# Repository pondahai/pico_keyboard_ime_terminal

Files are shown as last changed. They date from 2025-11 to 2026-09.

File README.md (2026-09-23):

# pico_keyboard_ime_terminal

**版本:** 1.8.0 (多分頁 UI 重構)  
**建置:** 里程碑 3.1 除錯建置 (v2.2 - Tag ID 記錄)

本文件旨在深入說明 PicoType Keyboard 韌體的內部架構、核心演算法與設計理念，主要供開發者與技術愛好者參考。

## 核心技術特點

此專案在資源有限的微控制器 (MCU) 上實現了複雜的中文輸入、圖形化介面與網路通訊功能，其核心技術包含以下幾點：

### 1. 模組化 UI 框架 (分頁系統)

為了應對日益複雜的功能，v1.8.0 版本引入了一套基於函式指標 (Function Pointer) 的分頁系統，取代了原有的 `enum` 狀態機。

*   **`Tab` 結構體:**
    ```c++
    struct Tab {
      const char* name;
      DrawFunction draw_func;
      InputHandler input_handler;
    };
    ```    此結構體定義了一個 UI 分頁，其中包含分頁名稱、一個指向其專屬**繪圖函式**的指標 (`draw_func`)，以及一個指向其**按鍵處理函式**的指標 (`input_handler`)。

*   **運作機制:**
    系統透過一個全域索引 `g_current_tab_index` 來追蹤目前作用中的分頁。主迴圈中的 `drawUI()` 和 `processKeyEvent()` 函式會根據此索引，從 `g_tabs[]` 陣列中呼叫對應的繪圖與輸入處理函式。
    ```c++
    // 繪圖時
    g_tabs[g_current_tab_index].draw_func();

    // 處理按鍵時
    g_tabs[g_current_tab_index].input_handler(finalKeyCode);
    ```

*   **優勢:** 這種設計具備高度可擴展性。新增一個功能分頁（例如「設定」或「地圖」）只需：
    1.  撰寫其對應的繪圖與輸入處理函式。
    2.  在 `g_tabs[]` 陣列中新增一筆 `Tab` 實體。
    無需修改核心的 UI 調度邏輯。

### 2. 高效能中文注音輸入法引擎 (IME)

`ImeEngine` 類別是實現中文輸入的核心。它採用了針對嵌入式系統優化的兩階段查詢演算法，以在極低的記憶體佔用下實現快速的字詞查詢。

*   **資料結構:** 所有輸入法資料（注音索引、字詞庫）都被預先處理並儲存在 `PROGMEM`（程式記憶體）中，由 `picotype_data_optimized.h` 引入。
    *   `zhuyin_idx_opt[]`: 注音查詢索引表。每一項包含一個指向字詞庫中「查詢鍵」的指標 (`key_offset`) 和長度，以及指向候選字詞資料的指標 (`data_offset`) 和長度。此索引表**已預先按查詢鍵的字母序排序**。
    *   `zhuyin_pool_opt[]`: 包含所有查詢鍵與候選字詞的巨大字串池。

*   **查詢流程:**
    1.  **按鍵轉注音:** `mapKeyToBopomofo()` 將鍵盤輸入 (如 "su3") 轉換為 UTF-8 注音符號 (如 "ㄙㄨˇ")，用於在螢幕上顯示。
    2.  **注音格式化為查詢鍵:** `formatBopomofoToKey()` 將注音符號轉換為用於在索引中查找的標準化查詢鍵 (如將 "ㄙㄨˇ" 轉換為 "ㄙㄨ3")。聲調被統一轉換為數字 `1`-`5` 並置於尾部，以利於排序與搜尋。
    3.  **二分搜尋 (Binary Search):** `binarySearch()` 函式在已排序的 `zhuyin_idx_opt` 索引表中對查詢鍵執行二分搜尋。這是在數千筆資料中實現毫秒級查找的關鍵。
    4.  **提取候選字:** 一旦找到匹配的索引記錄，便根據記錄中的 `data_offset` 和 `data_len` 從 `zhuyin_pool_opt` 字串池中直接讀取對應的候選字詞字串，並返回給上層 UI 顯示。

### 3. 優化的中文字型渲染

`FontRenderer` 類別負責將 UTF-8 編碼的字串（包含 ASCII 與中文字元）渲染到 ILI9341 螢幕上。

*   **資料結構:**
    *   `font_map_opt[]`: 字型映射表。每一項包含一個 Unicode 碼點，以及該字元在點陣資料池中的偏移量、寬度、高度和繪製偏移等資訊。此映射表**已預先按 Unicode 碼點排序**。
    *   `font_bitmap_data_opt[]`: 儲存所有字元點陣圖資料的巨型位元組陣列。

*   **渲染流程:**
    1.  **UTF-8 解碼:** `decodeUtf8()` 將輸入的字串逐字元解碼為 32 位元的 Unicode 碼點。
    2.  **ASCII 快速路徑:** 如果 Unicode 小於 128，則直接使用 `Adafruit_GFX` 內建的字型進行繪製，效率更高。
    3.  **中文字元查找:** 對於非 ASCII 字元，`findChar()` 函式會在 `font_map_opt` 中執行**二分搜尋**，快速定位該 Unicode 對應的字型資訊。
    4.  **點陣繪製:** 找到字元資訊後，`drawChar()` 函式會使用 `memcpy_P` 從 `PROGMEM` 中將點陣資料高效地複製到一個 RAM 緩衝區 (`g_char_bitmap_buffer`)，然後逐點將其繪製到 TFT 螢幕上。

### 4. Meshtastic Protobuf 通訊協定處理

裝置透過 UART 與 Meshtastic 節點通訊，所有資料交換均遵循其 Protobuf 序列化格式。

*   **封包結構:** Meshtastic 韌體使用一個簡單的封包格式來傳輸 Protobuf 資料：
    `[0x94, 0xc3]` (起始位元組) + `[Len_H, Len_L]` (2位元組長度) + `[Payload]` (Protobuf 資料)

*   **接收與解碼 (`handleProtoRx`):**
    此函式是一個狀態機，用於解析 UART 上接收到的位元組流。
    1.  等待 `0x94` 和 `0xc3` 起始位元組。
    2.  讀取接下來的兩個位元組，組合成承載資料的長度。
    3.  讀取指定長度的承載資料到 `proto_rx_buffer`。
    4.  使用 `nanopb` 的 `pb_decode()` 函式將緩衝區內的二進位資料反序列化為 `meshtastic_FromRadio` 結構體。
    5.  根據結構體中的 `which_payload_variant` 欄位（Tag ID），判斷封包類型（如 `my_info_tag`, `node_info_tag`, `packet_tag` 等），並分派給相應的處理邏輯（如更新節點資料庫、在聊天視窗顯示訊息等）。

*   **編碼與傳送:**
    傳送資料的流程相反。例如 `sendProtobufTextMessage()`:
    1.  建立一個 `meshtastic_ToRadio` 結構體。
    2.  填充需要傳送的資料（目標 ID、訊息內容等）。
    3.  使用 `nanopb` 的 `pb_encode()` 函式將結構體序列化為位元組流，存入 `proto_tx_buffer`。
    4.  依照上述封包結構，加上起始位元組和長度資訊，透過 `Serial1.write()` 傳送出去。

### 5. 硬體抽象 (鍵盤掃描)

鍵盤矩陣的掃描是透過兩顆移位暫存器（74HC595 負責輸出掃描訊號，74HC165 負責讀取按鍵狀態）完成的。

*   `updateKeyboardAndLeds_TwoPulse()` 函式負責整個掃描週期。它透過 `shiftOut` 向 74HC595 傳送資料來依序啟用鍵盤的每一列，同時也順便更新了 LED 的狀態。
*   在啟用每一列後，透過自訂的 `myShiftIn` 函式從 74HC165 讀回該列上所有按鍵的狀態。
*   為了處理硬體設計上的時序問題，函式中使用了兩次 Latch Pin 的脈衝 (`digitalWrite(LATCH_PIN, ...)`), 確保資料能被正確鎖存和讀取。

## 程式碼結構

*   **全域物件與變數:**
    *   `tft`, `renderer`, `ime`: 核心功能的類別實體。
    *   `g_tabs[]`, `g_current_tab_index`: UI 框架的核心。
    *   `g_node_db[]`, `g_channels[]`: Meshtastic 網路的本地資料快取。
    *   `inputBuffer_keys`, `editor_content`: 輸入與編輯區的狀態緩衝區。

*   **主要流程 (`setup()` & `loop()`):**
    *   `setup()`: 初始化硬體、序列埠、顯示器，並載入初始狀態。
    *   `loop()`:
        1.  處理 Protobuf/Terminal 的序列埠接收。
        2.  定期執行 Protobuf 的心跳與握手重試。
        3.  呼叫 `updateKeyboardAndLeds_TwoPulse()` 掃描鍵盤。
        4.  比較本次與上次的按鍵狀態，若有變化則呼叫 `processKeyEvent()` 進行處理。
        5.  更新 `lastKeyState` 狀態。
        6.  若 `needs_redraw` 旗標為真，則呼叫 `drawUI()` 更新螢幕。

## 編譯與依賴

*   **函式庫:**
    *   `Adafruit_GFX` & `Adafruit_ILI9341`: 顯示驅動。
    *   `nanopb`: Google Protobuf 的嵌入式 C 語言實現。
*   **核心資料檔案:**
    *   `picotype_data_optimized.h`: **極為關鍵**。此檔案包含了由外部工具預先處理好的字型點陣、字元映射表、注音索引與字詞庫。缺少此檔案，專案將無法編譯。
*   **Protobuf 生成檔案:**
    *   `mesh.pb.h`, `channel.pb.h` 等檔案需要從 Meshtastic 專案的 `.proto` 定義檔，使用 `nanopb_generator.py` 工具生成。

## 硬體 Pinout

| 功能 | 接腳 (GPIO) | 說明 |
| :--- | :--- | :--- |
| **TFT 顯示器** | | |
| CS | 17 | 片選 |
| RST | 21 | 重置 |
| DC | 20 | 資料/命令 |
| BLK | 22 | 背光控制 |
| **鍵盤移位暫存器** | | |
| DATA_OUT | 15 | 序列資料輸出 (至 74HC595) |
| LATCH | 14 | 鎖存訊號 |
| CLOCK | 26 | 時脈訊號 |
| DATA_IN | 27 | 序列資料輸入 (自 74HC165) |
| **UART 通訊** | | |
| TX | 0 | 至 Meshtastic 裝置的 RX |
| RX | 1 | 至 Meshtastic 裝置的 TX |

## 授權

本專案自身的程式碼採 **MIT**，見 [`LICENSE`](LICENSE)。

`picotype_data_optimized.h` 是**衍生資料**，同時包含第三方的字型點陣與注音碼表，
其聲明必須隨著散布。完整內容見 [`THIRD_PARTY_NOTICES.md`](THIRD_PARTY_NOTICES.md)，
摘要如下：

| 成分 | 上游 | 授權 |
| :--- | :--- | :--- |
| 注音碼表（`zhuyin_*` 陣列） | [McBopomofo](https://github.com/openvanilla/McBopomofo)（小麥注音輸入法） | MIT，Copyright (c) 2011-2026 Mengjuei Hsieh et al. |
| 中文字型（`font_*` 陣列） | Cubic 11（俐方體十一號）+ Fusion Pixel 12px | SIL OFL 1.1 |

碼表使用的是 `BPMFBase.txt`（單字注音）與 `BPMFPunctuations.txt`（標點），
兩者在上游皆無額外出處註記。帶有 libtabe（BSD）血統的是多字詞庫
`BPMFMappings.txt` —— **本專案未使用**（這裡是單字候選，不是詞庫）。

> ⚠️ **關於編譯後的韌體**：本 repo 不含 `.pb.c` / `.pb.h`，需自行以
> `nanopb_generator.py` 從 [meshtastic/protobufs](https://github.com/meshtastic/protobufs)
> 產生，而該專案為 **GPL-3.0**。因此**編譯出來的韌體二進位檔整體是 GPL-3.0**。
> MIT 與 GPL-3.0 相容，此組合合法，只是散布該二進位檔時須遵守 GPL-3.0。

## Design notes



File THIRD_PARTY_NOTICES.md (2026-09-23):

# Third-Party Notices

本專案的 `picotype_data_optimized.h` 是**衍生資料**,不是手寫的程式碼。
它由 [ime-charset-font-bitmap](https://github.com/pondahai/ime-charset-font-bitmap)
的建置管線產生,內容同時包含第三方的**字型點陣資料**與**注音碼表資料**。

散布本專案(含編譯後的韌體)時,以下聲明必須隨著一起散布。

---

## 1. 注音輸入法碼表 — McBopomofo(小麥注音輸入法)

| | |
|---|---|
| 上游 | https://github.com/openvanilla/McBopomofo |
| 授權 | MIT License |
| 著作權 | Copyright (c) 2011-2026 Mengjuei Hsieh et al. |

### 實際使用的檔案

| 檔案 | 內容 | 有無額外上游出處 |
|---|---|---|
| `Source/Data/BPMFBase.txt` | 單字注音對應 | 無 —— 適用 McBopomofo 的 MIT |
| `Source/Data/BPMFPunctuations.txt` | 標點符號對應 | 無 —— 適用 McBopomofo 的 MIT |

### 明確未使用的檔案

`Source/Data/BPMFMappings.txt`(2–6 字的多字詞庫)**未被使用**。

這點值得寫明:依 McBopomofo 的 `Source/Data/README.md`,該檔案
*"Originally simplified from tsi.src of libtabe (BSD Licensed) with modifications"*
——它帶有 libtabe 的 BSD 血統。

本專案的輸入法是**單字候選**而非詞庫,只取用了 `BPMFBase.txt` 與
`BPMFPunctuations.txt`,因此不涉及 libtabe,亦無 BSD 條款需要遵循。

### 資料在本專案中的形式

原始碼表為文字格式,經建置管線轉換為「索引 + 資料池」的二進位結構,
以 `zhuyin_idx_raw_opt[]` 與 `zhuyin_pool_opt[]` 兩個陣列存在於
`picotype_data_optimized.h`。此為格式轉換,內容仍為 McBopomofo 的衍生著作。

### MIT License 全文

```
MIT License

Copyright (c) 2011-2026 Mengjuei Hsieh et al.

Permission is hereby granted, free of charge, to any person obtaining a copy
of this software and associated documentation files (the "Software"), to deal
in the Software without restriction, including without limitation the rights
to use, copy, modify, merge, publish, distribute, sublicense, and/or sell
copies of the Software, and to permit persons to whom the Software is
furnished to do so, subject to the following conditions:

The above copyright notice and this permission notice shall be included in all
copies or substantial portions of the Software.

THE SOFTWARE IS PROVIDED "AS IS", WITHOUT WARRANTY OF ANY KIND, EXPRESS OR
IMPLIED, INCLUDING BUT NOT LIMITED TO THE WARRANTIES OF MERCHANTABILITY,
FITNESS FOR A PARTICULAR PURPOSE AND NONINFRINGEMENT. IN NO EVENT SHALL THE
AUTHORS OR COPYRIGHT HOLDERS BE LIABLE FOR ANY CLAIM, DAMAGES OR OTHER
LIABILITY, WHETHER IN AN ACTION OF CONTRACT, TORT OR OTHERWISE, ARISING FROM,
OUT OF OR IN CONNECTION WITH THE SOFTWARE OR THE USE OR OTHER DEALINGS IN THE
SOFTWARE.
```

---

## 2. 中文字型點陣資料

`picotype_data_optimized.h` 內的 `font_map_raw_opt[]` 與
`font_bitmap_data_1bpp[]` 是由下列字型光柵化產生的點陣資料。

| 字型 | 授權 | 角色 |
|---|---|---|
| [Cubic 11](https://github.com/ACh-K/Cubic-11)(俐方體十一號)v1.430 | SIL OFL 1.1 | 主字型 |
| [Fusion Pixel 12px zh_hant](https://github.com/TakWolf/fusion-pixel-font) | SIL OFL 1.1 | fallback |

依 SIL OFL 1.1,散布衍生資料時須隨附授權文字。完整的字型出處、版本固定理由
與保留字型名稱說明,見上游 repo 的 `fonts/LICENSES/ATTRIBUTION.md`。

> **保留字型名稱(Reserved Font Name)**:Cubic 保留「Cubic」「俐方體」。
> 本專案的產出不得以這些名稱對外呈現為字型名,故衍生檔案採中性命名
> (`picotype_*`)。

---

## 3. Meshtastic protobuf 與 Nanopb(本 repo 未收錄,但編譯時必要)

本 repo **不含**任何 `.pb.c` / `.pb.h` 或 nanopb 原始碼 ——
依 README,這些檔案由使用者自行以 `nanopb_generator.py` 從上游產生。

| 元件 | 上游 | 授權 |
|---|---|---|
| Meshtastic `.proto` 定義 | [meshtastic/protobufs](https://github.com/meshtastic/protobufs) | **GPL-3.0** |
| Nanopb(執行期與產生器) | [nanopb/nanopb](https://github.com/nanopb/nanopb) | Zlib,Copyright (c) 2011 Petteri Aimonen |

> ⚠️ **關於編譯後的韌體**
>
> 本 repo 自身的程式碼採 MIT。但 Meshtastic 的 protobuf 定義為 GPL-3.0,
> 因此**把本專案與那些產生檔一起編譯出來的韌體二進位檔,整體是 GPL-3.0**。
>
> MIT 與 GPL-3.0 相容(MIT 程式碼可被納入 GPL 作品),所以這個組合是合法的
> ——只是散布該二進位檔時要遵守 GPL-3.0,而不是 MIT。

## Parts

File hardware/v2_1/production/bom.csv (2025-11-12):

Designator | Footprint | Quantity | Value | LCSC Part #
BT1 | JST_PH_B2B-PH-K_1x02_P2.00mm_Vertical | 1 | Li-Poly PH2.0
C1, C2, C3 | 0805 | 3 | 100n
C10, C11, C9 | 0805 | 3 | 100nF
C12 | 1206 | 1 | 100nF
C4 | 0805 | 1 | 33n
C5, C6 | 0805 | 2 | 100n/10u
C7 | 0805 | 1 | 1u
C8 | 0805 | 1 | 1u/NC
D1, D10, D11, D12, D13, D14, D15, D16, D17, D18, D19, D2, D20, D21, D22, D23, D24, D25, D26, D27, D28, D29, D3, D30, D31, D32, D33, D34, D35, D36, D37, D38, D39, D4, D40, D41, D42, D43, D44, D45, D46, D47, D48, D49, D5, D50, D51, D52, D53, D54, D55, D56, D57, D58, D59, D6, D60, D61, D62, D7, D8, D9 | D_0805_JUMPER | 62 | 1N4148
D63 | LED_D3.0mm_Clear | 1 | ㄅ
D64 | LED_D3.0mm_Clear | 1 | ENG
D65 | 0805 | 1 | charge
J1 | PinHeader_1x07_P2.54mm_Horizontal | 1 | Conn_01x07
J10 | sd-card | 1 | Micro_SD_Card
J2 | STP0280A1-240320 | 1 | STP0280A1-240320-18P
J3 | PinSocket_1x07_P2.54mm_Horizontal | 1 | KEYBOARD
J4 | PinSocket_1x04_P2.54mm_Horizontal | 1 | UART
J5 | PinHeader_1x04_P2.54mm_Vertical | 1 | I2C Oled screen
J6 | audiojack-3.5mm-5p | 1 | AudioJack3_SwitchTR
J7 | SolderWire-0.1sqmm_1x02_P3.6mm_D0.4mm_OD1mm | 1 | speaker
J8 | Hirose_DF13-02P-1.25DSA_1x02_P1.25mm_Vertical | 1 | speaker
J9 | PinHeader_1x04_P2.54mm_Vertical | 1 | GPS Pins
M1 | HT-RA62 RA-01SH LoRa radio | 1 | HT-RA62_/_RA-01SH_LoRa_radio
M2 | ProMicro nrf52840 | 1 | ProMicro_NRF52840
M3 | LoRa-ESP32-V3 | 1 | ESP32_LORA_V3
M4 | T114 | 1 | T114_V2
Q1 | SOT-23_Handsoldering | 1 | 2N7002
Q2 | SOT-23_Handsoldering | 1 | DMG2305UX
R1, R2 | R_Axial_DIN0204_L3.6mm_D1.6mm_P7.62mm_Horizontal_0805 | 2 | R_US
R10 | 0805 | 1 | 0/15k
R11 | 0805 | 1 | 0/NC
R12, R13 | 0805 | 2 | 12k/100
R14 | 0805 | 1 | NC/10k
R15, R18 | 0805 | 2 | 10k
R16, R17 | 0805 | 2 | 10M
R19 | 1206 | 1 | 1k
R3 | 0805 | 1 | 330
R4, R7 | 0805 | 2 | 10k
R5 | 0805 | 1 | 5k1
R6 | 0805 | 1 | 1k
R8 | 0805 | 1 | 270
R9 | 0805 | 1 | NC/150
RN1, RN2 | R_Array_Convex_4x0603 | 2 | 10K
RN3 | R_Array_Convex_4x0603 | 1 | 10
RN4, RN5 | R_Array_Convex_4x0603 | 2 | 47k
RV1 | potentiometre disk 5pin | 1 | 10k
SW1 | SW_Push_1P1T_NO_CK_KSC7xxJ | 1 | 1 ! ㄅ
SW10 | SW_Push_1P1T_NO_CK_KSC7xxJ | 1 | E ㄍ
SW11 | SW_Push_1P1T_NO_CK_KSC7xxJ | 1 | D ㄎ
SW12 | SW_Push_1P1T_NO_CK_KSC7xxJ | 1 | C ㄏ
SW13 | SW_Push_1P1T_NO_CK_KSC7xxJ | 1 | 4 $ ˋ
SW14 | SW_Push_1P1T_NO_CK_KSC7xxJ | 1 | R ㄐ
SW15 | SW_Push_1P1T_NO_CK_KSC7xxJ | 1 | F ㄑ
SW16 | SW_Push_1P1T_NO_CK_KSC7xxJ | 1 | V ㄒ
SW17 | SW_Push_1P1T_NO_CK_KSC7xxJ | 1 | 5 % ㄓ
SW18 | SW_Push_1P1T_NO_CK_KSC7xxJ | 1 | T ㄔ
SW19 | SW_Push_1P1T_NO_CK_KSC7xxJ | 1 | G ㄕ
SW2 | SW_Push_1P1T_NO_CK_KSC7xxJ | 1 | Q ㄆ
SW20 | SW_Push_1P1T_NO_CK_KSC7xxJ | 1 | B ㄖ
SW21 | SW_Push_1P1T_NO_CK_KSC7xxJ | 1 | 6 ^ ˊ
SW22 | SW_Push_1P1T_NO_CK_KSC7xxJ | 1 | Y ㄗ
SW23 | SW_Push_1P1T_NO_CK_KSC7xxJ | 1 | H ㄘ
SW24 | SW_Push_1P1T_NO_CK_KSC7xxJ | 1 | N ㄙ
SW25 | SW_Push_1P1T_NO_CK_KSC7xxJ | 1 | 7 & ˙
SW26 | SW_Push_1P1T_NO_CK_KSC7xxJ | 1 | U ㄧ
SW27 | SW_Push_1P1T_NO_CK_KSC7xxJ | 1 | J ㄨ
SW28 | SW_Push_1P1T_NO_CK_KSC7xxJ | 1 | M ㄩ
SW29 | SW_Push_1P1T_NO_CK_KSC7xxJ | 1 | 8 * ㄚ
SW3 | SW_Push_1P1T_NO_CK_KSC7xxJ | 1 | A ㄇ
SW30 | SW_Push_1P1T_NO_CK_KSC7xxJ | 1 | I ㄛ
SW31 | SW_Push_1P1T_NO_CK_KSC7xxJ | 1 | K ㄜ
SW32 | SW_Push_1P1T_NO_CK_KSC7xxJ | 1 | , < ㄝ
SW33 | SW_Push_1P1T_NO_CK_KSC7xxJ | 1 | 9 ( ㄞ
SW34 | SW_Push_1P1T_NO_CK_KSC7xxJ | 1 | O ㄟ
SW35 | SW_Push_1P1T_NO_CK_KSC7xxJ | 1 | L ㄠ
SW36 | SW_Push_1P1T_NO_CK_KSC7xxJ | 1 | . > ㄡ
SW37 | SW_Push_1P1T_NO_CK_KSC7xxJ | 1 | 0 ) ㄢ
SW38 | SW_Push_1P1T_NO_CK_KSC7xxJ | 1 | P ㄣ
SW39 | SW_Push_1P1T_NO_CK_KSC7xxJ | 1 | ; : ㄤ
SW4 | SW_Push_1P1T_NO_CK_KSC7xxJ | 1 | Z ㄈ
SW40 | SW_Push_1P1T_NO_CK_KSC7xxJ | 1 | / ? ㄥ
SW41 | SW_Push_1P1T_NO_CK_KSC7xxJ | 1 | - _ ㄦ
SW42 | SW_Push_1P1T_NO_CK_KSC7xxJ | 1 | [ {
SW43 | SW_Push_1P1T_NO_CK_KSC7xxJ | 1 | ' "
SW44 | SW_Push_1P1T_NO_CK_KSC7xxJ | 1 | SHIFT
SW45 | SW_Push_1P1T_NO_CK_KSC7xxJ | 1 | = +
SW46 | SW_Push_1P1T_NO_CK_KSC7xxJ | 1 | ] }
SW47 | SW_Push_1P1T_NO_CK_KSC7xxJ | 1 | ENTER
SW48 | SW_Push_1P1T_NO_CK_KSC7xxJ | 1 | SPACE
SW49 | SW_Push_1P1T_NO_CK_KSC7xxJ | 1 | ` ~
SW5 | SW_Push_1P1T_NO_CK_KSC7xxJ | 1 | 2 @ ㄉ
SW50 | SW_Push_1P1T_NO_CK_KSC7xxJ | 1 | TAB
SW51 | SW_Push_1P1T_NO_CK_KSC7xxJ | 1 | CAPS
SW52 | SW_Push_1P1T_NO_CK_KSC7xxJ | 1 | CTRL
SW53 | SW_Push_1P1T_NO_CK_KSC7xxJ | 1 | ALT
SW54 | SW_Push_1P1T_NO_CK_KSC7xxJ | 1 | BACK
SW55 | SW_Push_1P1T_NO_CK_KSC7xxJ | 1 | \
SW56 | SW_Push_1P1T_NO_CK_KSC7xxJ | 1 | PGUP
SW57 | SW_Push_1P1T_NO_CK_KSC7xxJ | 1 | PGDN
SW58 | SW_Push_1P1T_NO_CK_KSC7xxJ | 1 | ⇧
SW59 | SW_Push_1P1T_NO_CK_KSC7xxJ | 1 | ⇩
SW6 | SW_Push_1P1T_NO_CK_KSC7xxJ | 1 | W ㄊ
SW60 | SW_Push_1P1T_NO_CK_KSC7xxJ | 1 | ⇦
SW61 | SW_Push_1P1T_NO_CK_KSC7xxJ | 1 | ⇨
SW62 | SW_Push_1P1T_NO_CK_KSC7xxJ | 1 | ESC
SW63 | SW_Push_1P1T_NO_CK_KSC7xxJ | 1 | bb up
SW64 | SW_CuK_JS202011AQN_DPDT_Angled | 1 | POWER
SW65 | SW_Push_1P1T_NO_CK_KSC7xxJ | 1 | bb down
SW66 | SW_Push_1P1T_NO_CK_KSC7xxJ | 1 | bb left
SW67 | SW_Push_1P1T_NO_CK_KSC7xxJ | 1 | bb right
SW68 | SW_Push_1P1T_NO_CK_KSC7xxJ | 1 | bb a
SW69 | SW_Push_1P1T_NO_CK_KSC7xxJ | 1 | bb b
SW7 | SW_Push_1P1T_NO_CK_KSC7xxJ | 1 | S ㄋ
SW70 | SW_Push_1P1T_NO_CK_KSC7xxJ | 1 | bb c
SW71 | SW_Push_1P1T_NO_CK_KSC7xxJ | 1 | bb d
SW72 | skrp | 1 | RUN
SW75 | skrp | 1 | RST
SW76 | skrp | 1 | BTN
SW8 | SW_Push_1P1T_NO_CK_KSC7xxJ | 1 | X ㄌ
SW9 | SW_Push_1P1T_NO_CK_KSC7xxJ | 1 | 3 # ˇ
TP1 | TestPoint_Pad_D1.5mm | 1 | BL_P22
TP10, TP15 | TestPoint_Pad_D1.5mm | 2 | Q2
TP11 | TestPoint_Pad_D1.5mm | 1 | Q3
TP12 | TestPoint_Pad_D1.5mm | 1 | Q4
TP13 | TestPoint_Pad_D1.5mm | 1 | Q5
TP14 | TestPoint_Pad_D1.5mm | 1 | Q6
TP16 | TestPoint_Pad_D1.5mm | 1 | MOSI_P11
TP17 | TestPoint_Pad_D1.5mm | 1 | MISO_P12
TP18 | TestPoint_Pad_D1.5mm | 1 | CS_P13
TP19 | TestPoint_Pad_D1.5mm | 1 | SCK_P10
TP2 | TestPoint_Pad_D1.5mm | 1 | VBUS
TP3 | TestPoint_Pad_D1.5mm | 1 | VSYS
TP4 | TestPoint_Pad_D1.5mm | 1 | S
TP5 | TestPoint_Pad_D1.5mm | 1 | D
TP6 | TestPoint_THTPad_5.0x5.0mm_Drill2.0mm | 1 | VBAT
TP7 | TestPoint_THTPad_5.0x5.0mm_Drill2.0mm | 1 | GND
TP8 | TestPoint_Pad_D1.5mm | 1 | SND_P7
TP9 | TestPoint_Pad_D1.5mm | 1 | sound
U1, U4 | SOIC-16_3.9x9.9mm_P1.27mm | 2 | 74HC595
U2 | SOIC-16_3.9x9.9mm_P1.27mm | 1 | 74HC165
U3 | RaspberryPi_Pico_W_SMD_HandSolder | 1 | Pico
U5 | SOT-23-5 | 1 | MCP73831-2-OT
U6 | SOIC-8_3.9x4.9mm_P1.27mm | 1 | HT6872
U7 | SOIC-8-1EP_3.9x4.9mm_P1.27mm_EP2.41x3.3mm | 1 | XB8089D0

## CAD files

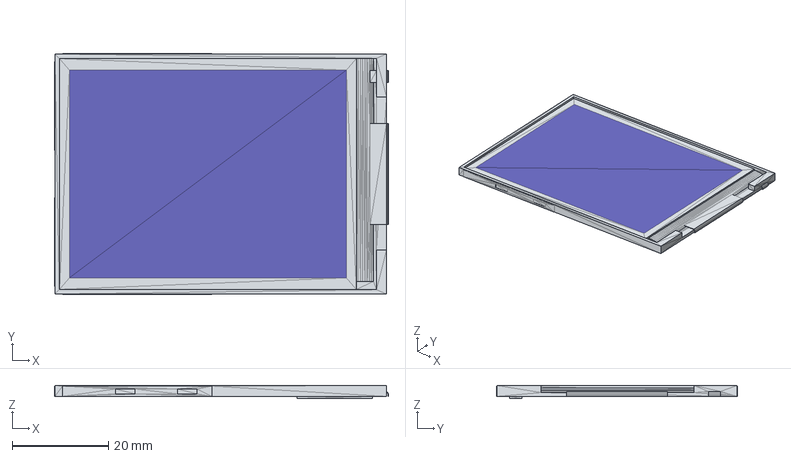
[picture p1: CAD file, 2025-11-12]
hardware/v2_1/2.8 TFT Module001.007.0.step
69.5 x 50.1 x 2.72 mm
__8_TFT_Module001_007_003
__8_TFT_Module001_007_004
__8_TFT_Module001_007_005
__8_TFT_Module001_007_006
__8_TFT_Module001_007_007
__8_TFT_Module001_007_008
__8_TFT_Module001_007_009
__8_TFT_Module001_007_010
__8_TFT_Module001_007_011
__8_TFT_Module001_007_012
__8_TFT_Module001_007_013
__8_TFT_Module001_007_014
__8_TFT_Module001_007_015
__8_TFT_Module001_007_016
__8_TFT_Module001_007_017
__8_TFT_Module001_007_018
__8_TFT_Module001_007_019
__8_TFT_Module001_007_020
__8_TFT_Module001_007_021
__8_TFT_Module001_007_022
__8_TFT_Module001_007_023
__8_TFT_Module001_007_024
__8_TFT_Module001_007_025
__8_TFT_Module001_007_026
__8_TFT_Module001_007_027
__8_TFT_Module001_007_028
__8_TFT_Module001_007_029
__8_TFT_Module001_007_030
__8_TFT_Module001_007_031
__8_TFT_Module001_007_032
__8_TFT_Module001_007_033
__8_TFT_Module001_007_034
__8_TFT_Module001_007_035
__8_TFT_Module001_007_036
__8_TFT_Module001_007_037
__8_TFT_Module001_007_038
__8_TFT_Module001_007_039
__8_TFT_Module001_007_040
__8_TFT_Module001_007_041
__8_TFT_Module001_007_042
__8_TFT_Module001_007_043
__8_TFT_Module001_007_044
__8_TFT_Module001_007_045
__8_TFT_Module001_007_046
__8_TFT_Module001_007_047
__8_TFT_Module001_007_048
__8_TFT_Module001_007_049
__8_TFT_Module001_007_050
__8_TFT_Module001_007_051
__8_TFT_Module001_007_052
__8_TFT_Module001_007_053
__8_TFT_Module001_007_054
__8_TFT_Module001_007_055
__8_TFT_Module001_007_056
__8_TFT_Module001_007_057
__8_TFT_Module001_007_058
__8_TFT_Module001_007_059
__8_TFT_Module001_007_060
__8_TFT_Module001_007_061
__8_TFT_Module001_007_062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

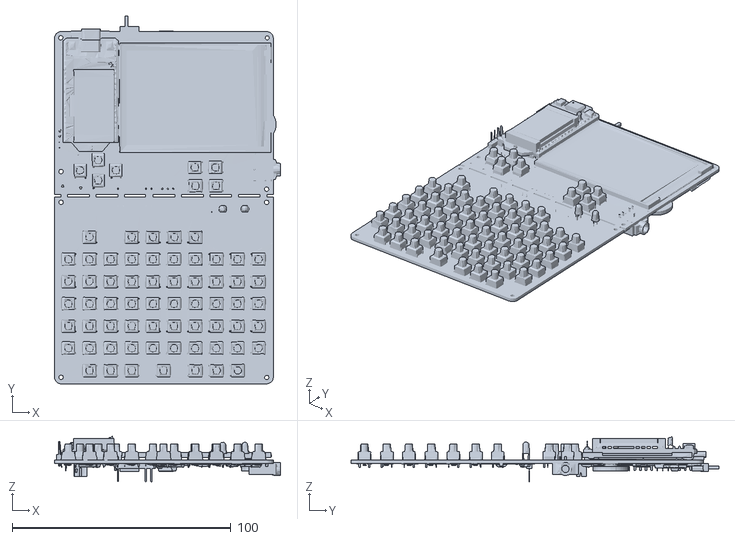
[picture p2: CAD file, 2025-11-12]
hardware/v2_1/v2_1.stl
103.3 x 168.1 x 20.8

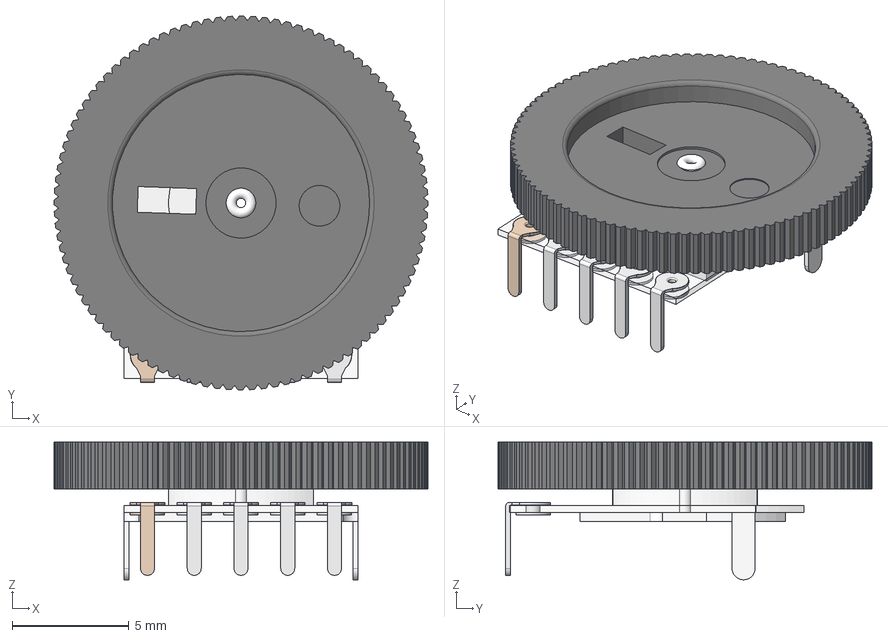
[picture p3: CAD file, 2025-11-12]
hardware/v2_1/potentiometre disk 5pin.step
16.0 x 16.0 x 5.89 mm
brochage
supp metalliq
disque
pin
pin001
pin002
pin003
pin004

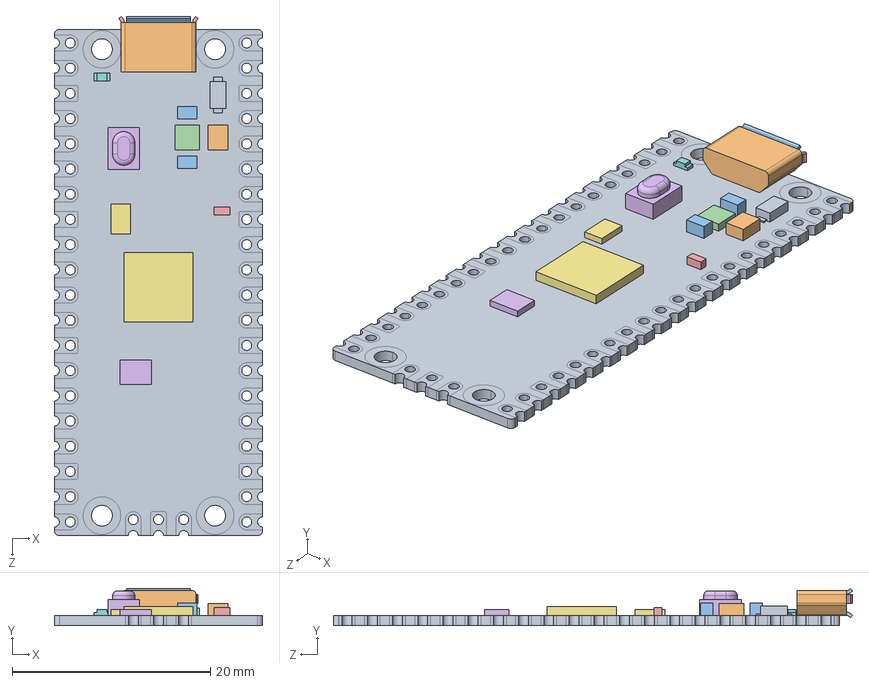
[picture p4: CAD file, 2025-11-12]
hardware/v2_1/Pico-R3.step
21.0 x 3.73 x 52.3 mm
PICO_REF_BOARD.STEP
PICO_REF_USB.STEP
PICO_REF_SWITCH.STEP
PICO_REF_MICROCONTROLLER.STEP
PICO_REF_LED.STEP
PICO_REF_ONSEMI.STEP
PICO_BOURNS.STEP
PICO_MURATA.STEP x 2
PICO_RICHTEK.STEP
PICO_DIODES.STEP
PICO_AEL.STEP
PICO_WINBOND.STEP

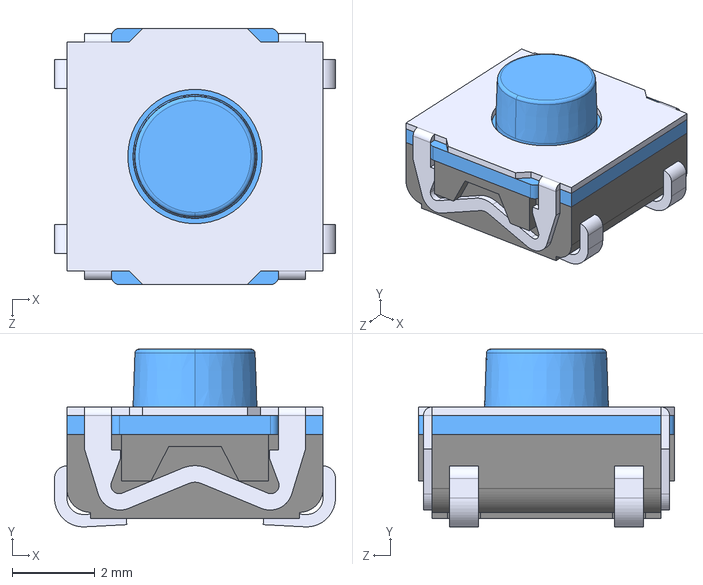
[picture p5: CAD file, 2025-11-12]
hardware/v2_1/KSC741J LFS.STEP
6.80 x 4.30 x 6.20 mm

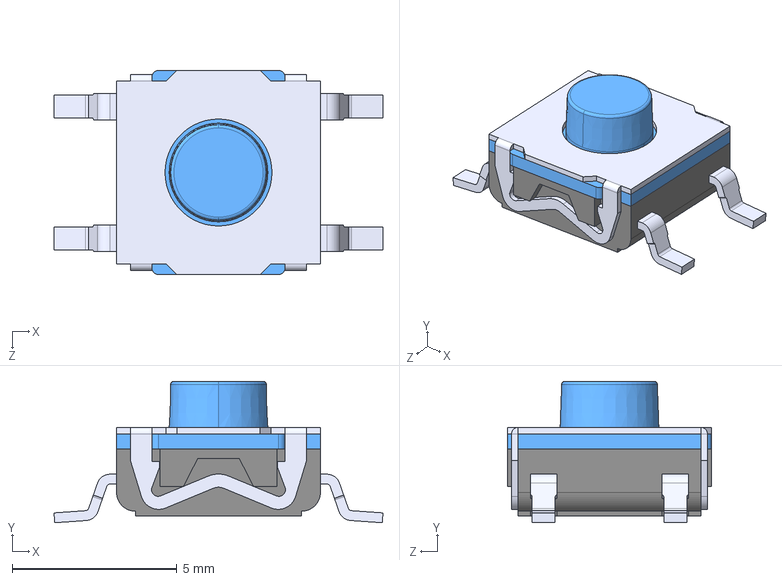
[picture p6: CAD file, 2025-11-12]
hardware/v2_1/KSC741G LFS.STEP
10.0 x 4.30 x 6.20 mm

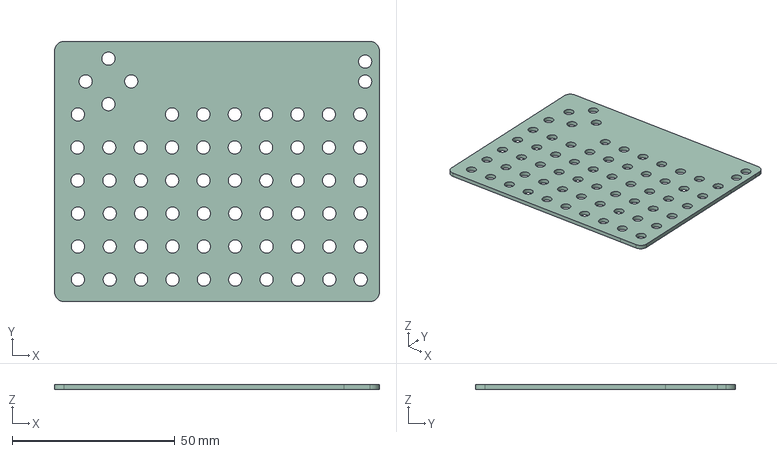
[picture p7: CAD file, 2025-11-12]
hardware/v2_1/v2_keyboard_cover.step
100.0 x 80.1 x 1.60 mm

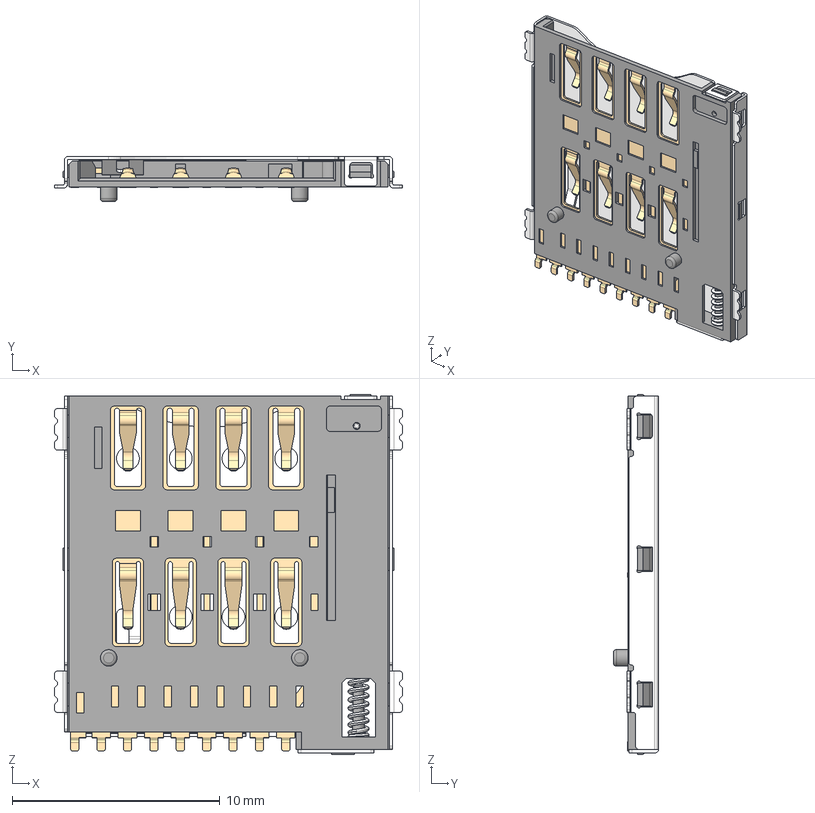
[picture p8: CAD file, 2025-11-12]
hardware/v2_1/SIM7100-8-1-15-00-A.stp
16.8 x 2.18 x 17.3 mm
SIM7100-8-1-15-00-A_PART3
SIM7100-8-1-15-00-A_PART2
SIM7100-8-1-15-00-A_PART1

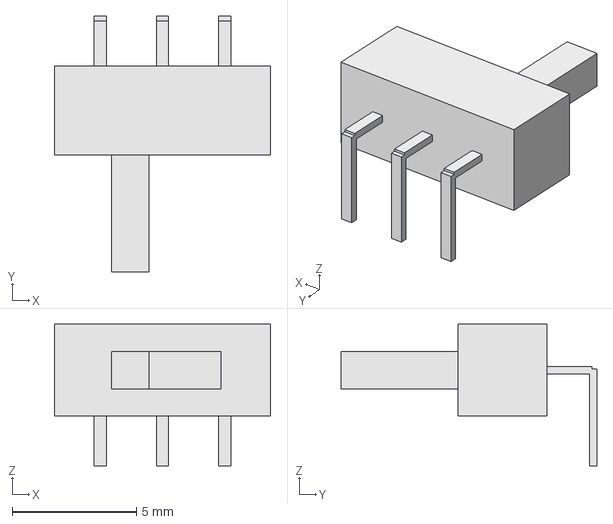
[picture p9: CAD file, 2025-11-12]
hardware/v2_1/ss-12d03.step
8.70 x 10.3 x 5.70 mm

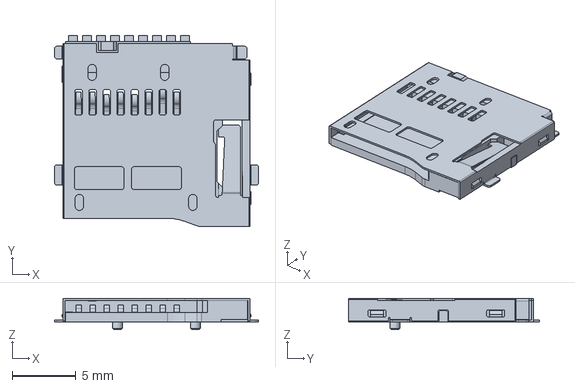
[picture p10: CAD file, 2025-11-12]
hardware/v2_1/MICRO_SD_CARD_SOCKET.step
16.0 x 15.0 x 2.44 mm

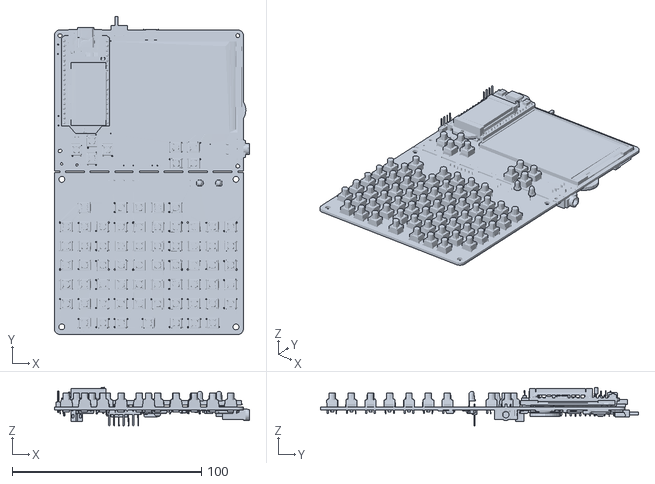
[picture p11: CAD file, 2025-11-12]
hardware/v2_1/v2_1 1.stl
103.3 x 168.1 x 20.5

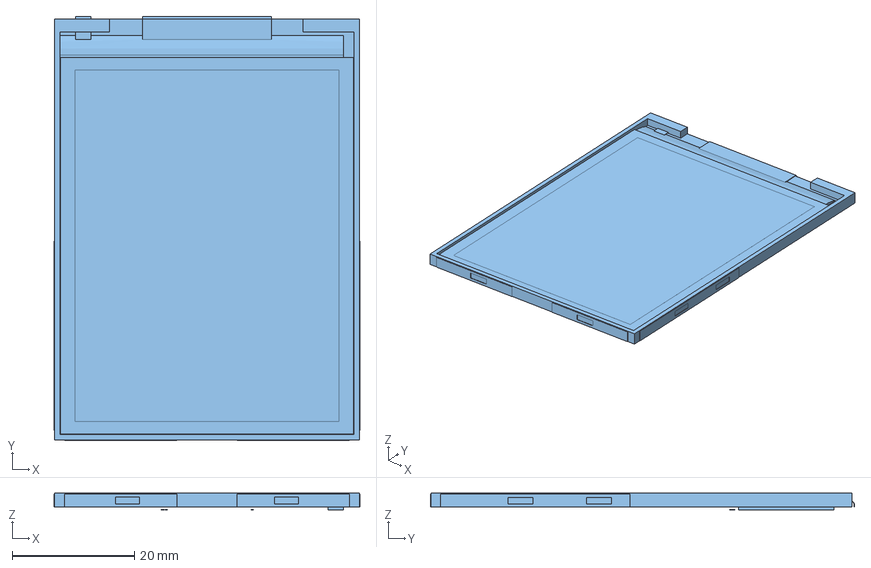
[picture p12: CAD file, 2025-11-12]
hardware/v2_1/2.8 TFT Module001.5.step
50.1 x 69.5 x 2.72 mm

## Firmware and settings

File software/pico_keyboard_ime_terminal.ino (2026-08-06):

// ==========================================================================
//
//   PicoType Keyboard - Standalone Chinese Input & Display Device
//   Version: 1.8.0 (Multi-Tab UI Refactor)
//   Milestone 3.1 Debugging Build (v2.2 - Tag ID Logging)
//
// ==========================================================================

// --- 包含所有必要的函式庫 ---
#include "picotype_data_optimized.h"
#include <Adafruit_GFX.h>
#include <Adafruit_ILI9341.h>
#include <SPI.h>
#include <string.h>
#include <Arduino.h>

// --- Protobuf 函式庫 ---
#include "pb.h"
#include "pb_encode.h"
#include "pb_decode.h"
#include "mesh.pb.h"
#include "channel.pb.h"

// ==========================================================================
// --- 硬體與 UI 配置 ---
// ==========================================================================
#define TFT_CS 17
#define TFT_RST 21
#define TFT_DC 20
#define TFT_BLK 22
const int DATA_OUT_PIN = 15;
const int LATCH_PIN = 14;
const int CLOCK_PIN = 26;
const int DATA_IN_PIN = 27;
#define UART_TX_PIN 0
#define UART_RX_PIN 1
#define UART_BAUDRATE 38400
#define COLOR_BACKGROUND ILI9341_BLACK
#define COLOR_TEXT ILI9341_WHITE
#define COLOR_INPUT ILI9341_YELLOW
#define COLOR_CANDIDATE ILI9341_CYAN
#define COLOR_CYAN ILI9341_CYAN
#define COLOR_BORDER 0x39E7
#define COLOR_HINT ILI9341_GREEN
#define COLOR_OUTPUT ILI9341_WHITE
#define COLOR_STATUS_ONLINE ILI9341_GREEN
#define COLOR_STATUS_STALE ILI9341_YELLOW
#define COLOR_STATUS_OFFLINE 0x7BEF  // Dark Grey
const int FONT_HEIGHT = 16;
const int PADDING = 4;
const int MARGIN = 5;
const int LINE_SPACING = 4;
// 缺字時的前進量。全形字的 x_advance 是 13，用 FONT_HEIGHT / 2 = 8 會讓
// drawString 與 getStringWidth 算出不同的寬度，導致排版錯位。
const int FULLWIDTH_ADVANCE = 13;
// 由字型資料自行宣告，隨 build_font.py 的產出自動調整。
// 舊的 1 B/px 標頭檔沒有這個巨集，會在此編譯失敗 —— 這是刻意的防呆。
#define MAX_CHAR_BUFFER_SIZE PICOTYPE_MAX_GLYPH_BYTES
uint8_t g_char_bitmap_buffer[MAX_CHAR_BUFFER_SIZE];
#define PROTO_BUFFER_SIZE 512
uint8_t proto_tx_buffer[PROTO_BUFFER_SIZE];
uint8_t proto_rx_buffer[PROTO_BUFFER_SIZE];

// ==========================================================================
// --- 鍵盤按鍵定義與 Keymap ---
// ==========================================================================
#define KEY_NULL 0
#define KEY_SHIFT_R 202
#define KEY_ENTER 203
#define KEY_BACKSPACE 204
#define KEY_CTRL_L 205
#define KEY_TAB 206
#define KEY_ESC 207
#define KEY_CAPS_LOCK 208
#define KEY_UP_ARROW 209
#define KEY_DOWN_ARROW 210
#define KEY_LEFT_ARROW 211
#define KEY_RIGHT_ARROW 212
#define KEY_PGUP 213
#define KEY_PGDOWN 214
#define KEY_ALT 215

const char keymap_base[8][8] = {
  { '1', '3', '5', '7', '9', '-', KEY_TAB, KEY_BACKSPACE },
  { 'q', 'e', 't', 'u', 'o', '[', KEY_ESC, '\\' },
  { 'a', 'd', 'g', 'j', 'l', '\'', KEY_CTRL_L, KEY_CAPS_LOCK },
  { 'z', 'c', 'b', 'm', '.', KEY_SHIFT_R, KEY_DOWN_ARROW, KEY_NULL },
  { '2', '4', '6', '8', '0', '=', '`', KEY_NULL },
  { 'w', 'r', 'y', 'i', 'p', ']', KEY_UP_ARROW, KEY_PGUP },
  { 's', 'f', 'h', 'k', ';', KEY_ENTER, KEY_RIGHT_ARROW, KEY_PGDOWN },
  { 'x', 'v', 'n', ',', '/', ' ', KEY_LEFT_ARROW, KEY_ALT }
};
const char keymap_shifted[8][8] = {
  { '!', '#', '%', '&', '(', '_', '-', KEY_BACKSPACE },
  { 'Q', 'E', 'T', 'U', 'O', '{', KEY_ESC, '\\' },
  { 'A', 'D', 'G', 'J', 'L', '"', KEY_CTRL_L, KEY_CAPS_LOCK },
  { 'Z', 'C', 'B', 'M', '>', KEY_SHIFT_R, KEY_DOWN_ARROW, KEY_NULL },
  { '@', '$', '^', '*', ')', '+', '~', KEY_NULL },
  { 'W', 'R', 'Y', 'I', 'P', '}', KEY_UP_ARROW, KEY_PGUP },
  { 'S', 'F', 'H', 'K', ':', KEY_ENTER, KEY_RIGHT_ARROW, KEY_PGDOWN },
  { 'X', 'V', 'N', '<', '?', ' ', KEY_LEFT_ARROW, KEY_ALT }
};

// ==========================================================================
// --- 資料模型與 UI 狀態定義 ---
// ==========================================================================
// enum UIView { VIEW_MAIN_CHAT, VIEW_NODE_LIST, VIEW_NODE_DETAILS, VIEW_CHANNEL_LIST }; // [UI REFACTOR] Replaced by Tab system
struct MyInfo {
  uint32_t node_num;
  char pio_env[40];
  uint32_t reboot_count;
};
struct Node {
  uint32_t num;
  char long_name[40];
  char short_name[5];
  meshtastic_HardwareModel hw_model;
  uint32_t last_heard;
  float snr;
  bool has_position;
  int32_t latitude_i;
  int32_t longitude_i;
};
#define MAX_NODES 30
struct Channel {
  uint32_t index;
  meshtastic_ChannelSettings settings;
  meshtastic_Channel_Role role;
};
#define MAX_CHANNELS 8
Channel g_channels[MAX_CHANNELS];
int g_channel_count = 0;
int g_channel_list_selection = 0;

// ==========================================================================
// --- 類別定義 (無變動) ---
// ==========================================================================
class FontRenderer {
public:
  FontRenderer(Adafruit_ILI9341& display)
    : _tft(display) {}
  void drawString(int16_t x, int16_t y, const char* text, uint16_t color, uint16_t bg = COLOR_BACKGROUND) {
    if (bg != COLOR_BACKGROUND) _tft.fillRect(x, y, getStringWidth(text), FONT_HEIGHT + 2, bg);
    int16_t cursor_x = x;
    for (int i = 0; text[i] != '\0';) {
      uint32_t unicode;
      int char_len = decodeUtf8(text + i, &unicode);
      if (char_len == 0) {
        i++;
        continue;
      }
      if (unicode < 128) {
        _tft.setCursor(cursor_x, y + FONT_HEIGHT - 12);
        _tft.setTextColor(color);
        _tft.print((char)unicode);
        cursor_x += 6;
      } else {
        const FontMapRecord_Opt* record = findChar(unicode);
        if (record) {
          drawChar(cursor_x, y, color, record, g_char_bitmap_buffer);
          cursor_x += pgm_read_byte(&record->x_advance);
        } else {
          _tft.drawRect(cursor_x + 2, y + 2, FONT_HEIGHT - 4, FONT_HEIGHT - 4, ILI9341_MAGENTA);
          cursor_x += FULLWIDTH_ADVANCE;
        }
      }
      i += char_len;
    }
  }
  int getStringWidth(const char* text) {
    int16_t total_width = 0;
    for (int i = 0; text[i] != '\0';) {
      uint32_t unicode;
      int char_len = decodeUtf8(text + i, &unicode);
      if (char_len == 0) {
        i++;
        continue;
      }
      if (unicode < 128) total_width += 6;
      else {
        const FontMapRecord_Opt* record = findChar(unicode);
        if (record) total_width += pgm_read_byte(&record->x_advance);
        else total_width += FULLWIDTH_ADVANCE;
      }
      i += char_len;
    }
    return total_width;
  }
  int decodeUtf8(const char* s, uint32_t* unicode) {
    if ((*s & 0x80) == 0) {
      *unicode = *s;
      return 1;
    }
    if ((*s & 0xE0) == 0xC0) {
      *unicode = ((uint32_t)(s[0] & 0x1F) << 6) | (s[1] & 0x3F);
      return 2;
    }
    if ((*s & 0xF0) == 0xE0) {
      *unicode = ((uint32_t)(s[0] & 0x0F) << 12) | ((uint32_t)(s[1] & 0x3F) << 6) | (s[2] & 0x3F);
      return 3;
    }
    return 0;
  }
private:
  Adafruit_ILI9341& _tft;
  const FontMapRecord_Opt* findChar(uint32_t unicode) {
    int low = 0;
    int high = font_map_count_opt - 1;
    while (low <= high) {
      int mid = low + (high - low) / 2;
      uint32_t mid_unicode = pgm_read_dword(&font_map_opt[mid].unicode);
      if (mid_unicode == unicode) return &font_map_opt[mid];
      if (mid_unicode < unicode) low = mid + 1;
      else high = mid - 1;
    }
    return nullptr;
  }
  void drawChar(int16_t x, int16_t y, uint16_t color, const FontMapRecord_Opt* record, uint8_t* bitmap_buffer) {
    uint8_t w = pgm_read_byte(&record->width), h = pgm_read_byte(&record->height);
    int8_t x_off = pgm_read_byte(&record->x_offset), y_off = pgm_read_byte(&record->y_offset);
    uint32_t offset = pgm_read_dword(&record->offset);
    if (w == 0 || h == 0) return;
    // 1 bit/pixel, row-aligned, LSB-first：每列佔 stride 個位元組，
    // 第 i 個 pixel 位於 byte i / 8 的 bit i % 8。
    uint8_t stride = (w + 7) / 8;
    size_t buffer_size = (size_t)stride * h;
    if (buffer_size > MAX_CHAR_BUFFER_SIZE) return;
    memcpy_P(bitmap_buffer, font_bitmap_data_1bpp + offset, buffer_size);
    int16_t draw_x = x + x_off, draw_y = y + y_off;
    _tft.startWrite();
    for (int16_t j = 0; j < h; j++) {
      const uint8_t* row = bitmap_buffer + (size_t)j * stride;
      for (int16_t i = 0; i < w; i++)
        if (row[i >> 3] >> (i & 7) & 1) _tft.writePixel(draw_x + i, draw_y + j, color);
    }
    _tft.endWrite();
  }
};
class ImeEngine {
public:
  ImeEngine() {}
  bool query(const char* inputCode, char* resultBuffer, size_t bufferSize) {
    char bopomofoBuffer[32] = { 0 };
    if (!mapKeyToBopomofo(inputCode, bopomofoBuffer, sizeof(bopomofoBuffer))) return false;
    char queryKey[12] = { 0 };
    formatBopomofoToKey(bopomofoBuffer, queryKey, sizeof(queryKey));
    const ImeIndexRecord_Opt* resultRecord = binarySearch(queryKey);
    if (resultRecord) {
      uint16_t offset = pgm_read_word(&resultRecord->data_offset);
      uint16_t length = pgm_read_word(&resultRecord->data_len);
      if (length >= bufferSize) length = bufferSize - 1;
      memcpy_P(resultBuffer, zhuyin_pool_opt + offset, length);
      resultBuffer[length] = '\0';
      return true;
    }
    return false;
  }
  static bool mapKeyToBopomofo(const char* input, char* output, size_t outputSize) {
    output[0] = '\0';
    for (int i = 0; input[i] != '\0'; ++i) {
      char tempBuf[4] = { 0 };
      if (keyToBopomofoChar(input[i], tempBuf)) {
        if (strlen(output) + strlen(tempBuf) < outputSize) strcat(output, tempBuf);
        else return false;
      }
    }
    return true;
  }
private:
  static int keyToBopomofoChar(char key, char* buf) {
    char lower_key = tolower(key); // <-- 新增此行，將傳入的 key 轉為小寫
    if (lower_key == '1') {
      strcpy(buf, "ㄅ");
      return 3;
    }
    if (lower_key == 'q') {
      strcpy(buf, "ㄆ");
      return 3;
    }
    if (lower_key == 'a') {
      strcpy(buf, "ㄇ");
      return 3;
    }
    if (lower_key == 'z') {
      strcpy(buf, "ㄈ");
      return 3;
    }
    if (lower_key == '2') {
      strcpy(buf, "ㄉ");
      return 3;
    }
    if (lower_key == 'w') {
      strcpy(buf, "ㄊ");
      return 3;
    }
    if (lower_key == 's') {
      strcpy(buf, "ㄋ");
      return 3;
    }
    if (lower_key == 'x') {
      strcpy(buf, "ㄌ");
      return 3;
    }
    if (lower_key == 'e') {
      strcpy(buf, "ㄍ");
      return 3;
    }
    if (lower_key == 'd') {
      strcpy(buf, "ㄎ");
      return 3;
    }
    if (lower_key == 'c') {
      strcpy(buf, "ㄏ");
      return 3;
    }
    if (lower_key == 'r') {
      strcpy(buf, "ㄐ");
      return 3;
    }
    if (lower_key == 'f') {
      strcpy(buf, "ㄑ");
      return 3;
    }
    if (lower_key == 'v') {
      strcpy(buf, "ㄒ");
      return 3;
    }
    if (lower_key == '5') {
      strcpy(buf, "ㄓ");
      return 3;
    }
    if (lower_key == 't') {
      strcpy(buf, "ㄔ");
      return 3;
    }
    if (lower_key == 'g') {
      strcpy(buf, "ㄕ");
      return 3;
    }
    if (lower_key == 'b') {
      strcpy(buf, "ㄖ");
      return 3;
    }
    if (lower_key == 'y') {
      strcpy(buf, "ㄗ");
      return 3;
    }
    if (lower_key == 'h') {
      strcpy(buf, "ㄘ");
      return 3;
    }
    if (lower_key == 'n') {
      strcpy(buf, "ㄙ");
      return 3;
    }
    if (lower_key == 'u') {
      strcpy(buf, "ㄧ");
      return 3;
    }
    if (lower_key == 'j') {
      strcpy(buf, "ㄨ");
      return 3;
    }
    if (lower_key == 'm') {
      strcpy(buf, "ㄩ");
      return 3;
    }
    if (lower_key == '8') {
      strcpy(buf, "ㄚ");
      return 3;
    }
    if (lower_key == 'i') {
      strcpy(buf, "ㄛ");
      return 3;
    }
    if (lower_key == 'k') {
      strcpy(buf, "ㄜ");
      return 3;
    }
    if (lower_key == ',') {
      strcpy(buf, "ㄝ");
      return 3;
    }
    if (lower_key == '9') {
      strcpy(buf, "ㄞ");
      return 3;
    }
    if (lower_key == 'o') {
      strcpy(buf, "ㄟ");
      return 3;
    }
    if (lower_key == 'l') {
      strcpy(buf, "ㄠ");
      return 3;
    }
    if (lower_key == '.') {
      strcpy(buf, "ㄡ");
      return 3;
    }
    if (lower_key == '0') {
      strcpy(buf, "ㄢ");
      return 3;
    }
    if (lower_key == 'p') {
      strcpy(buf, "ㄣ");
      return 3;
    }
    if (lower_key == ';') {
      strcpy(buf, "ㄤ");
      return 3;
    }
    if (lower_key == '/') {
      strcpy(buf, "ㄥ");
      return 3;
    }
    if (lower_key == '-') {
      strcpy(buf, "ㄦ");
      return 3;
    }
    if (lower_key == '6') {
      strcpy(buf, "ˊ");
      return 3;
    }
    if (lower_key == '3') {
      strcpy(buf, "ˇ");
      return 3;
    }
    if (lower_key == '4') {
      strcpy(buf, "ˋ");
      return 3;
    }
    if (lower_key == '7') {
      strcpy(buf, "˙");
      return 3;
    }
    return 0;
  }
  void formatBopomofoToKey(const char* bopomofo, char* key, size_t keySize) {
    char* p_key = key;
    const char* p_bopo = bopomofo;
    bool hasTone = false;
    while (*p_bopo != '\0' && (p_key - key) < (keySize - 1)) {
      if (memcmp(p_bopo, "ˊ", 3) == 0) {
        *p_key++ = '2';
        p_bopo += 3;
        hasTone = true;
      } else if (memcmp(p_bopo, "ˇ", 3) == 0) {
        *p_key++ = '3';
        p_bopo += 3;
        hasTone = true;
      } else if (memcmp(p_bopo, "ˋ", 3) == 0) {
        *p_key++ = '4';
        p_bopo += 3;
        hasTone = true;
      } else if (memcmp(p_bopo, "˙", 3) == 0) {
        *p_key++ = '5';
        p_bopo += 3;
        hasTone = true;
      } else {
        memcpy(p_key, p_bopo, 3);
        p_key += 3;
        p_bopo += 3;
      }
    }
    if (!hasTone && (p_key - key) < (keySize - 1)) { *p_key++ = '1'; }
    *p_key = '\0';
  }
  const ImeIndexRecord_Opt* binarySearch(const char* key) {
    int low = 0, high = zhuyin_idx_count_opt - 1;
    while (low <= high) {
      int mid = low + (high - low) / 2;
      char key_from_pool[12] = { 0 };
      uint16_t key_offset = pgm_read_word(&zhuyin_idx_opt[mid].key_offset);
      uint8_t key_len = pgm_read_byte(&zhuyin_idx_opt[mid].key_len);
      memcpy_P(key_from_pool, zhuyin_pool_opt + key_offset, key_len);
      int cmp = strcmp(key, key_from_pool);
      if (cmp == 0) return &zhuyin_idx_opt[mid];
      else if (cmp < 0) high = mid - 1;
      else low = mid + 1;
    }
    return nullptr;
  }
};

// ==========================================================================
// --- 全域物件與變數 ---
// ==========================================================================
Adafruit_ILI9341 tft = Adafruit_ILI9341(TFT_CS, TFT_DC, TFT_RST);
MyInfo g_my_info;
Node g_node_db[MAX_NODES];
int g_node_count = 0;
int g_node_list_selection = 0;
ImeEngine ime;
FontRenderer* renderer = nullptr;
enum State { STATE_INPUT,
             STATE_SELECTION };
State currentState = STATE_INPUT;
String inputBuffer_keys = "", inputBuffer_bopomofo = "", candidate_string = "";
String editor_content = "--- PROTOBUF MODE ---\n";
int candidate_page = 0;
const int CANDIDATES_PER_PAGE = 9;
bool needs_redraw = true;
bool keyState[8][8], lastKeyState[8][8];
bool isShiftPressed = false, isAltPressed = false;
enum InputMode { MODE_LOWERCASE, MODE_UPPERCASE, MODE_BOPOMOFO };
InputMode g_input_mode = MODE_BOPOMOFO; // 預設開機為注音模式

bool isImeEnabled = true, isTerminalMode = false, isProtoMode = true;
String g_old_input_display = "", g_old_candidate_display = "", g_old_mode_hint = "";
bool g_device_responded = false;
unsigned long g_last_handshake_time = 0, g_last_heartbeat_time = 0;
const unsigned long HANDSHAKE_RETRY_INTERVAL = 5000, HEARTBEAT_INTERVAL = 15000;
uint32_t g_target_node_num = 0xFFFFFFFF;
String g_target_node_name = "廣播";
uint32_t g_last_sent_packet_id = 0;
String g_last_sent_line = "";
uint32_t g_current_unix_time = 0;

// --- [FEATURE] 名稱編輯機制 (方向鍵選擇版) ---
enum MyInfoTabState { MY_INFO_BROWSING, MY_INFO_EDITING };
MyInfoTabState g_my_info_tab_state = MY_INFO_BROWSING; // 目前分頁的狀態 (瀏覽或編輯)
int g_my_info_selection = 0;                          // 在瀏覽模式下，目前選擇的項目 (0=長名稱, 1=短名稱)
const int MY_INFO_EDITABLE_FIELDS = 2;                // 可編輯的欄位總數
String g_edit_buffer = "";
String g_my_long_name = "PicoType UI";
String g_my_short_name = "Pico";
// --- [FEATURE] 結束 ---

// --- [UI REFACTOR] 分頁系統定義 ---
typedef void (*DrawFunction)();
typedef void (*InputHandler)(char);

struct Tab {
  const char* name;
  DrawFunction draw_func;
  InputHandler input_handler;
};

int g_current_tab_index = 0;
bool g_is_node_detail_view_active = false;  // 用於節點分頁內的子視圖狀態

const int TAB_BAR_HEIGHT = FONT_HEIGHT + PADDING * 2;

// 函式原型宣告
void drawMainChatContent();
void drawNodeListContent();
void drawChannelListContent();
void drawMyInfoContent(); // <-- 新增
void handleMainChatInput(char keyCode);
void handleNodeListInput(char keyCode);
void handleChannelListInput(char keyCode);
void handleMyInfoInput(char keyCode); // <-- 新增

// 分頁陣列
Tab g_tabs[] = {
  { "聊天", drawMainChatContent, handleMainChatInput },
  { "節點", drawNodeListContent, handleNodeListInput },
  { "頻道", drawChannelListContent, handleChannelListInput },
  { "本機", drawMyInfoContent, handleMyInfoInput } // <-- 新增此行
};
const int g_tab_count = sizeof(g_tabs) / sizeof(Tab);
// --- [UI REFACTOR] 結束 ---


// ==========================================================================
// --- 輔助函式 (大部分無變動) ---
// ==========================================================================
void addMyInfoToNodeDB();
void updateNodeInDB(const meshtastic_NodeInfo& node_info);
int getUtf8CharLength(const char* s) {
  if ((*s & 0x80) == 0) return 1;
  if ((*s & 0xE0) == 0xC0) return 2;
  if ((*s & 0xF0) == 0xE0) return 3;
  if ((*s & 0xF8) == 0xF0) return 4;
  return 1;
}
int countUtf8Chars(String& str) {
  int count = 0;
  for (int i = 0; i < str.length();) {
    i += getUtf8CharLength(str.c_str() + i);
    count++;
  }
  return count;
}
int getNthUtf8CharByteIndex(String& str, int n) {
  if (n < 0) return -1;
  if (n == 0) return 0;
  int current_char_count = 0;
  for (int i = 0; i < str.length();) {
    if (current_char_count == n) return i;
    i += getUtf8CharLength(str.c_str() + i);
    current_char_count++;
  }
  if (current_char_count == n) return str.length();
  return -1;
}
byte myShiftIn(uint8_t dataPin, uint8_t clockPin) {
  byte data = 0;
  for (int i = 0; i < 8; i++) {
    if (digitalRead(dataPin)) { data |= (1 << i); }
    digitalWrite(clockPin, HIGH);
    delayMicroseconds(1);
    digitalWrite(clockPin, LOW);
  }
  return data;
}
void updateKeyboardAndLeds_TwoPulse() {
  for (int row = 0; row < 8; row++) {
    byte rowScanData = (1 << row);
    byte ledData = (isImeEnabled ? 1 : 0) | ((isTerminalMode || isProtoMode) ? 2 : 0);
    digitalWrite(LATCH_PIN, LOW);
    shiftOut(DATA_OUT_PIN, CLOCK_PIN, MSBFIRST, ledData);
    shiftOut(DATA_OUT_PIN, CLOCK_PIN, MSBFIRST, rowScanData);
    digitalWrite(LATCH_PIN, HIGH);
    delayMicroseconds(5);
    digitalWrite(LATCH_PIN, LOW);
    delayMicroseconds(1);
    digitalWrite(LATCH_PIN, HIGH);
    byte colData = myShiftIn(DATA_IN_PIN, CLOCK_PIN);
    for (int col = 0; col < 8; col++) keyState[row][7 - col] = (colData & (1 << col));
  }
}
void print_hex_buffer(const uint8_t* buffer, size_t len, const char* prefix = "") {
  Serial.print(prefix);
  for (size_t i = 0; i < len; i++) {
    if (buffer[i] < 0x10) Serial.print("0");
    Serial.print(buffer[i], HEX);
    Serial.print(" ");
  }
  Serial.println();
}
const char* getHwModelString(meshtastic_HardwareModel model) {
  switch (model) {
    case meshtastic_HardwareModel_TLORA_V2: return "T-LoRa V2";
    case meshtastic_HardwareModel_TBEAM: return "T-Beam";
    case meshtastic_HardwareModel_HELTEC_V2_1: return "Heltec V2.1";
    case meshtastic_HardwareModel_HELTEC_V3: return "Heltec V3";
    case meshtastic_HardwareModel_RAK4631: return "RAK4631";
    case meshtastic_HardwareModel_T_ECHO: return "T-Echo";
    case meshtastic_HardwareModel_LILYGO_TBEAM_S3_CORE: return "T-Beam S3";
    case meshtastic_HardwareModel_PRIVATE_HW: return "PicoType";
    case meshtastic_HardwareModel_UNSET:
    default: return "Unknown";
  }
}
const char* getChannelRoleString(meshtastic_Channel_Role role) {
  switch (role) {
    case meshtastic_Channel_Role_PRIMARY: return "PRIMARY";
    case meshtastic_Channel_Role_SECONDARY: return "SECONDARY";
    case meshtastic_Channel_Role_DISABLED: return "DISABLED";
    default: return "UNKNOWN";
  }
}
void addMyInfoToNodeDB() {
  if (g_my_info.node_num == 0) return;
  for (int i = 0; i < g_node_count; i++) {
    if (g_node_db[i].num == g_my_info.node_num) { return; }
  }
  if (g_node_count < MAX_NODES) {
    Node& selfNode = g_node_db[g_node_count];
    selfNode.num = g_my_info.node_num;
    strcpy(selfNode.long_name, "PicoType UI (Self)");
    strcpy(selfNode.short_name, "Me");
    selfNode.hw_model = meshtastic_HardwareModel_PRIVATE_HW;
    selfNode.last_heard = g_current_unix_time > 0 ? g_current_unix_time : 1;
    selfNode.snr = 0;
    selfNode.has_position = false;
    g_node_count++;
    needs_redraw = true;
  }
}
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
void loop() {
  if (isProtoMode) {
    while (Serial1.available() > 0) { handleProtoRx(); }
    if (!g_device_responded && (millis() - g_last_handshake_time > HANDSHAKE_RETRY_INTERVAL)) { sendProtoHandshake(); }
    if (g_device_responded && (millis() - g_last_heartbeat_time > HEARTBEAT_INTERVAL)) { sendHeartbeat(); }
  } else if (isTerminalMode && Serial1.available() > 0) {
    while (Serial1.available() > 0) {
      char incomingByte = Serial1.read();
      if (incomingByte == '\b' || incomingByte == 127) {
        if (editor_content.length() > 0) {
          int last_char_idx = getNthUtf8CharByteIndex(editor_content, countUtf8Chars(editor_content) - 1);
          if (last_char_idx != -1) editor_content.remove(last_char_idx);
        }
      } else {
        editor_content += incomingByte;
      }
    }
    needs_redraw = true;
  }

  updateKeyboardAndLeds_TwoPulse();

  for (int r = 0; r < 8; r++)
    for (int c = 0; c < 8; c++)
      if (keyState[r][c] != lastKeyState[r][c])
        processKeyEvent(r, c, keyState[r][c]);

  memcpy(lastKeyState, keyState, sizeof(keyState));
  drawUI();
}

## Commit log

2025-11-12 add v2_2
    [2.8 TFT Module001.007.0.step, 2.8 TFT Module001.5.step, KSC741G LFS.STEP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]
2026-08-06 FontRenderer 改用 1bpp 字型資料
    搭配 ime-charset-font-bitmap 的 1bpp 改造，字型資料從 1,420.3 KB 降到
    353.8 KB。drawChar() 改為位元解碼（row-aligned、LSB-first，
    stride = (w + 7) / 8）。
    符號一併更名 font_bitmap_data_opt -> font_bitmap_data_1bpp。這是刻意的
    防呆：舊的 1 B/px renderer 遇到新資料會編譯失敗，而不是畫出一片雪花。
    MAX_CHAR_BUFFER_SIZE 由固定值 256 改為綁定標頭檔宣告的
    PICOTYPE_MAX_GLYPH_BYTES（目前 26），緩衝區大小不再可能與資料脫節。
    一併修正缺字前進量：findChar() 回 nullptr 時原本前進 FONT_HEIGHT / 2 = 8，
    但全形字的 x_advance 是 13，導致 drawStrin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
    [pico_keyboard_ime_terminal.ino]
2026-08-06 更新字型資料：加入 Fusion Pixel fallback
    字型資料重新產生，加入 Fusion Pixel 12px 作為 fallback 層，補回 2,591 個
    Cubic 11 沒有的字（含 1,013 個簡體字）。收錄字數 10,229 → 12,820。
    font_bitmap_data_1bpp 219,046 → 275,790 B
    font_map_raw_opt 143,206 → 179,480 B
    合計 353.8 → 444.6 KB
    相對改造前的 1,420.3 KB 仍省 975.7 KB。
    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
2026-08-06 更新字型資料：收錄範圍改為三方聯集
    上游 (ime-charset-font-bitmap) 修正收錄範圍定義後重新產生。原本的範圍
    只依字表推導，漏掉 4,232 個「注音打得出來、字型也有字形、但字表沒收」
    的字 —— 它們在裝置上會顯示洋紅方框。
    收錄字數 12,820 → 17,052
    font_bitmap_data_1bpp 275,790 → 368,894 B
    font_map_raw_opt 179,480 → 238,728 B
    合計 444.6 → 593.4 KB
    相對改造前的 1,420.3 KB 仍省 827 KB。
    renderer 不需要改動：PICOTYPE_MAX_GLYPH_BYTES 仍為 26。
    尚未編譯或上機驗證。
2026-08-06 修正 link_status 緩衝區溢位
    drawChannelListContent() 內 char link_status[5] 被 strcpy "↑↓"。
    ↑ (U+2191) 與 ↓ (U+2193) 各佔 3 bytes UTF-8，兩者共 6 bytes，
    加結尾 NUL 需要 7 —— 溢位 2 bytes，蓋掉相鄰的堆疊變數。
    GCC 早有警告，只是混在既有的編譯輸出裡沒被注意到：
    warning: 'char* strcpy(char*, const char*)' writing 7 bytes into a
    region of size 5 overflows the destination [-Wstringop-overflow=]
    三個值全部是字串常值，改用 const char* 指標即可，不需要複製，
    也就沒有緩衝區大小可以算錯。
    與 1bpp 改造無關，是編譯驗證時順帶發現的既有問題。修正後重新編譯，
    s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
    [pico_keyboard_ime_terminal.ino]
2026-09-23 Add MIT license and third-party notices
    下游 repo 都指向這裡說「沒有 LICENSE、碼表出處未寫明」,現補齊。另註明本 repo 不含 .pb.* 檔,但編譯出的韌體因 Meshtastic protobuf (GPL-3.0) 整體為 GPL-3.0。

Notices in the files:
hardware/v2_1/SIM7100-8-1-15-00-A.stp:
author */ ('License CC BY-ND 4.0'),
